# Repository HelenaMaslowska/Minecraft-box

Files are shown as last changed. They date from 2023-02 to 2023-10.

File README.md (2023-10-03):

# Minecraft box
Minecraft box is made using Raspberry Pi Zero, Python, electronics detectors and cartoon. This is my project for studies and first one using Raspberry Pi! It tooks about 2 weeks.

### So, how it works:
1. First of all you need to put your card on the right and RFID detects if your card is valid.
2. Secondly you need to choose your minibox from 1 to 4 on your phone.
3. Thirdly write your numbers from your phone to the box and box checks if your type it correctly.
4. If password had been written corretly the minibox opens!
5. The box automatically close.

<p align="center">

<p>

## Plans, scheme
1. [plans](https://github.com/HelenaMaslowska/Minecraft-box/blob/main/Scheme/plan.png) (written in polish) - explain plan for connections between devices 
2. [state machine](https://github.com/HelenaMaslowska/Minecraft-box/blob/main/Scheme/Maszyna%20stan%C3%B3w.png) (written in polish) - explain plan of states
3. [scheme](https://github.com/HelenaMaslowska/Minecraft-box/blob/main/Scheme/scheme.png) - final version 

## Run these programs in startup
1. [server.py](https://github.com/HelenaMaslowska/Minecraft-box/blob/main/Programs/server.py)
2. [main.py](https://github.com/HelenaMaslowska/Minecraft-box/blob/main/Programs/main.py)

## Models
I made models which I printed on 3D Printer. Here is folder for them! [> folder <](https://github.com/HelenaMaslowska/Minecraft-box/tree/main/Models)

## Photos
You may see final and physical result of this project so here is some photos from inside the box:
<p align="center">
  
<br/>
<p align="left">And here is Raspberry Pi:<p>
<p align="center">
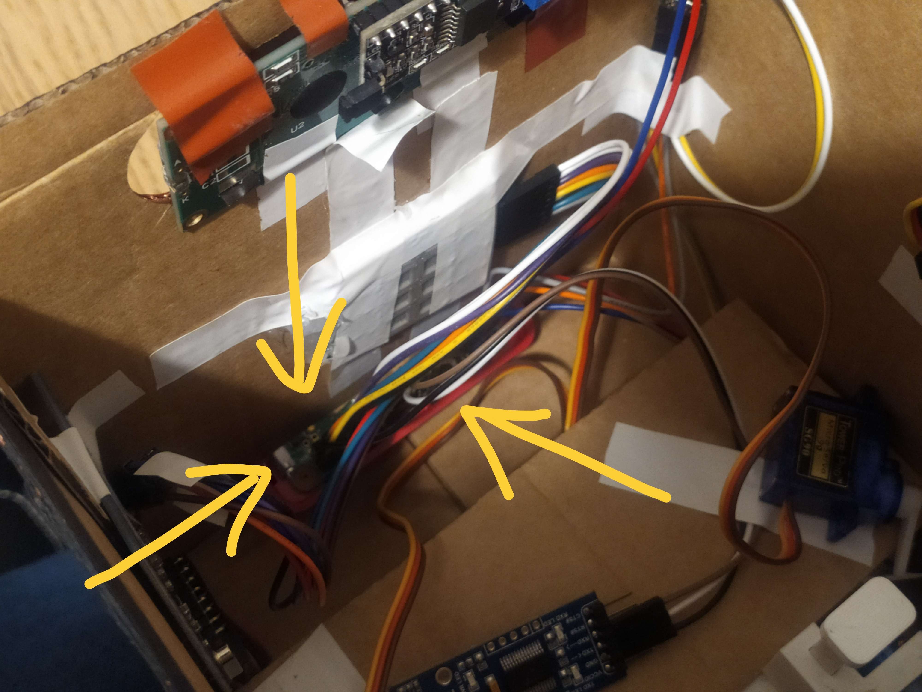
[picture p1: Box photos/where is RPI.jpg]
  
<p>

Outside the box:
<p align="center">

<br/>

<br/>
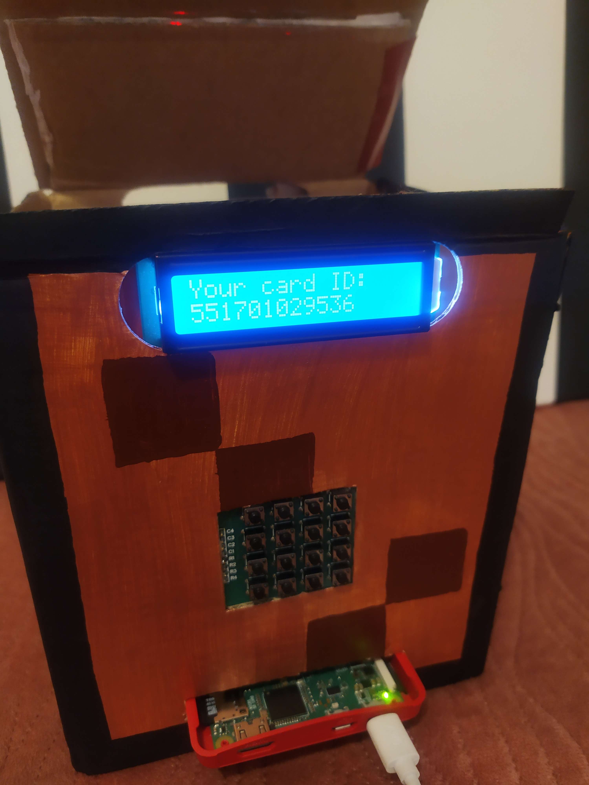
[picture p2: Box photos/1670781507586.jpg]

<p>

And the app:
<p align="center">
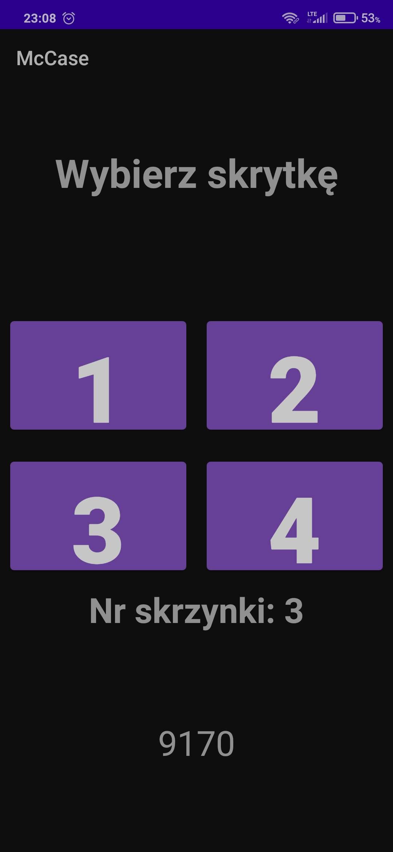
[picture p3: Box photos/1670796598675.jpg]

<p>
  
## Authors
- All electronics and graphics stuff, plans, state machine and scheme - Helena Masłowska
- Phone app - Łukasz Jankowski
  
Dec 2022

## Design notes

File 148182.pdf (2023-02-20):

### Laboratorium z przedmiotu Systemy wbudowane (SW) Sprawozdanie

Nazwa projektu: Skrzynka-self z Minecrafta

Prowadzący: Ariel Antonowicz | Autorzy: 148182 148081 150251 | Grupa dziekańska: | i5.1
| | Ocena:

Cel projektu:

Stworzenie skrzynki na przedmioty zabezpieczone jednorazowo wygenerowanym hasłem z telefonu (na zasadzie blik). Łączymy się za pomocą Wi-Fi i wpisujemy hasło, które następnie otwiera odpowiednią skrytkę. Skrytki nie mogą być otwarte jednocześnie. Buzzer odpala się 3 sekundy przed zamknięciem i kiedy zostało wpisane nieprawidłowe hasło.

Schemat:

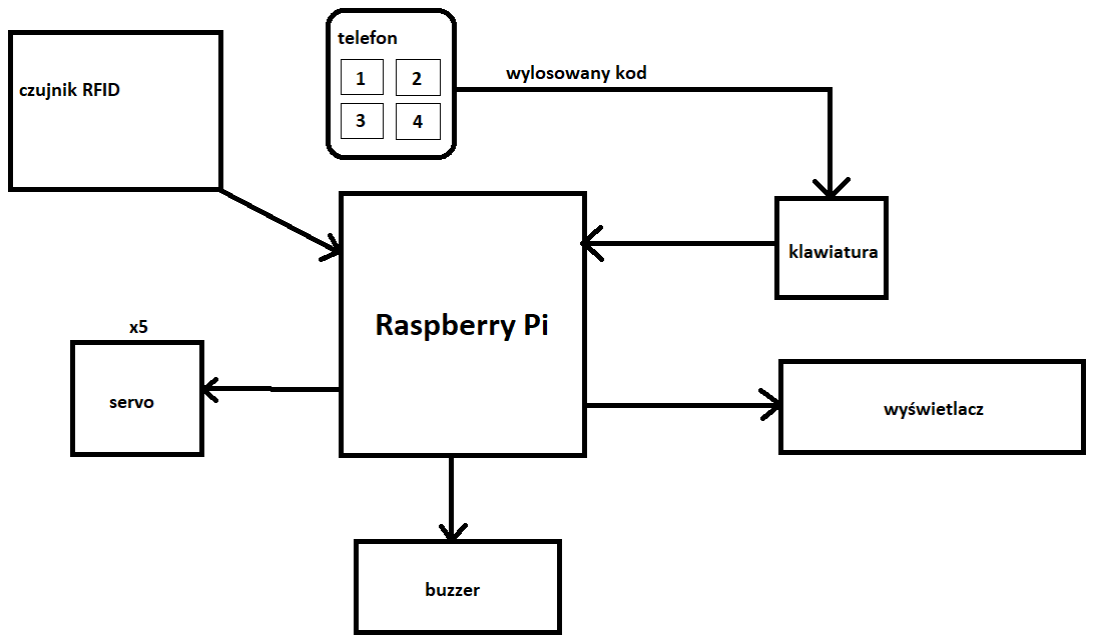
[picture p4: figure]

Wykorzystana platforma sprzętowa, czujniki pomiarowe, elementy wykonawcze:

servo x5, klawiatura, czujnik RFID, aplikacja na telefonie, buzzer

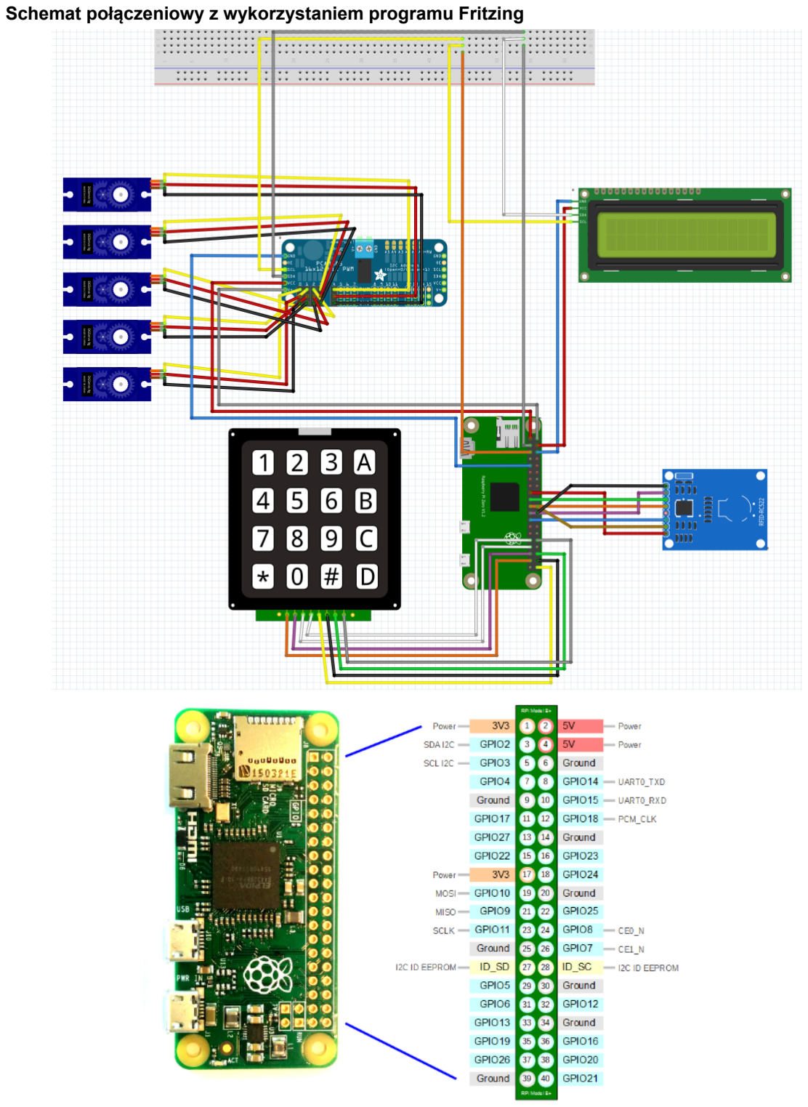
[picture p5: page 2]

Schemat połączeniowy z wykorzystaniem programu Fritzing

Wykorzystane elementy
- 1x Czytnik kart RFID RC522
- 1x 16 kanałowy servo motor driver
- 1x Wyświetlacz LCD 16X2 Alphanumeric Display
- 1x Raspberry Pi Zero W
- 1x 16-klawiszowa klawiatura 4x4 DWT-0261
- 3x Małe Servo SG90 9g
- 1x Małe ServoTG9e 9g
- 1x Duże Servo ACOMS AS-12

Projekt a realizacja
Z początku wgraliśmy na kartę SD Raspberry Pi OS. Następnie podłączyliśmy kartę do Raspberry Pi Zero W, które umożliwia łączenie się poprzez sieć Wi-Fi. Zamontowaliśmy czujniki i większość elementów. Mieliśmy problem z Pythonem (odinstalowano go, po czym zainstalowano, ale nie była to najlepsza decyzja). Pomogło ponowne wgranie systemu na kartę SD. Trzeba też było odpowiednio skonfigurować wstępne ustawienia i opcje (co będzie pokazane niżej).
Wszystkie elementy celu zostały spełnione poza ostatnim - buzzerem. Uznaliśmy, że jeśli servo wydaje dźwięki przy otwieraniu to nie potrzeba innego dźwięku, który oznajmia że coś się dzieje ze skrzynką, ponadto wszystko jest wyświetlane na ekranie.
Nie spodziewaliśmy się, że zostanie wykorzystane aż tyle pinów w Raspberry Pi stąd pomysł z driverem do serv. Dzięki temu wszystkie serva spokojnie mieszczą się na urządzeniu, a można również dołączyć większą liczbę serv niż 4.
Do projektu chcieliśmy dołączyć również płytkę umożliwiającą korzystanie z Raspberry Pi przewodowo ale okazała się nieprzydatna. Cały program został właściwie stworzony przez Putty - protokół SSH dzięki któremu mogliśmy pracować zdalnie poprzez tunel przekierowujący IP do localhosta w Raspberry Pi. Aplikacja na telefon została napisana w Kotlinie. Połączenie odbywa się poprzez udostępnienie telefonu jako routera i podłączenie aplikacji do IP Raspberry Pi. Aplikacja postuje na serwerze, która jest na płytce informacje o numerze skrytki i kodzie do tej skrytki a RPi to odbiera.

Możliwości rozwoju projektu
Skrzynka jest prototypem, który przypomina paczkomat. Wystarczy kliknąć odpowiedni przycisk na telefonie, a skrytka sama się otworzy. Można powiedzieć że stworzyliśmy paczkomat v2 z 4 skrytkami.

Najważniejsze fragmenty kodu z komentarzami

Pobrane biblioteki i inicjalizacja zmiennych

#!/usr/bin/python

# ------------ LIBRARIES SECTION ------------import time

import RPi.GPIO as GPIO
# server

import requests
# rfid

from mfrc522 import SimpleMFRC522 # LCD
from rpi_lcd import LCD
# keyboard

from pad4pi import rpi_gpio # servo driver
GPIO.setmode(GPIO.BCM)
GPIO.setwarnings(False)
import board
import busio
import adafruit_pca9685
from adafruit_servokit import ServoKit

# ------------ STARTER PACK STUFF SECTION ------------i2c = busio.I2C(board.SCL, board.SDA)

pca = adafruit_pca9685.PCA9685(i2c) | # driver
kit = ServoKit(channels=16) | # driver
pca.frequency = 50 | # set frequency for servos driver
card = SimpleMFRC522() | # rfid
lcd = LCD(address=0x3f) | # lcd
keyboard = "" | # keyboard input
KEYPAD = [
["1","2","3","A"],
["4","5","6","B"],
["7","8","9","C"],
["*","0","#","D"]
]
ROW_PINS = [21, 20, 16, 12] | # set pins BCM mode
COL_PINS = [26, 19, 13, 6] | # set pins BCM mode
factory = rpi_gpio.KeypadFactory()
keypad = factory.create_keypad(keypad=KEYPAD,row_pins=ROW_PINS, col_pins=COL_PINS, gpio_mode=GPIO.BCM)

Aktywacja klawiatury z dołączonej biblioteki

def activate_keyboard():
keypad.registerKeyPressHandler(key_pressed)

def key_pressed(key):
global keyboard
try:
keyboard += str(key)
except ValueError:
print("F")

Pobieranie danych z serwera

def get_from_server():
global server, case, code, if_open
server = eval(requests.get("http://0.0.0.0:8183").text) code, case = str(server['code']), int(server['case'])

Główny program

activate_keyboard() | # włączono odczytywanie klawiatury
while True:
set_servos() | # wyzerowanie pozycji serv na stan początkowy
try:
while str(keyboard) == "" or str(keyboard[len(keyboard)-1]) not in exit_btns: # tylko ostatnia litera inputu umożliwia wyjście ze skrzynki lcd_text("Hi! ", 1)
lcd_text("Put your card!", 2)
id, text = card.read() | # oczekiwanie na kartę
lcd_show_card_id()
if id == 551701029536: | # odczytywanie tylko jednej karty
id = 0
open_box() | # otworzenie skrzynki
time.sleep(4)
while str(keyboard) == "" or str(keyboard[len(keyboard)-1]) not in exit_btns:
get_from_server() # pobranie ostatnio wygenerowanego kodu check_if_wrong_password() # sprawdzenie czy wejście nie
# przekroczyło długości ciągu 4 cyfrowego PINu

lcd_show_password() | # odświeżenie ekranu
time.sleep(0.5) | # by nie zajmować zbytnio procesora

if str(code) == str(keyboard):
# post_info_to_the_server(code, case, "cant")

keyboard = ""
open_for_x_seconds(8) # ograniczony czas otwarcia skrzynki lcd_text("Thats all! ", 1)
lcd_text("THX!", 2)
time.sleep(3) | # chwila na przeczytanie tekstu

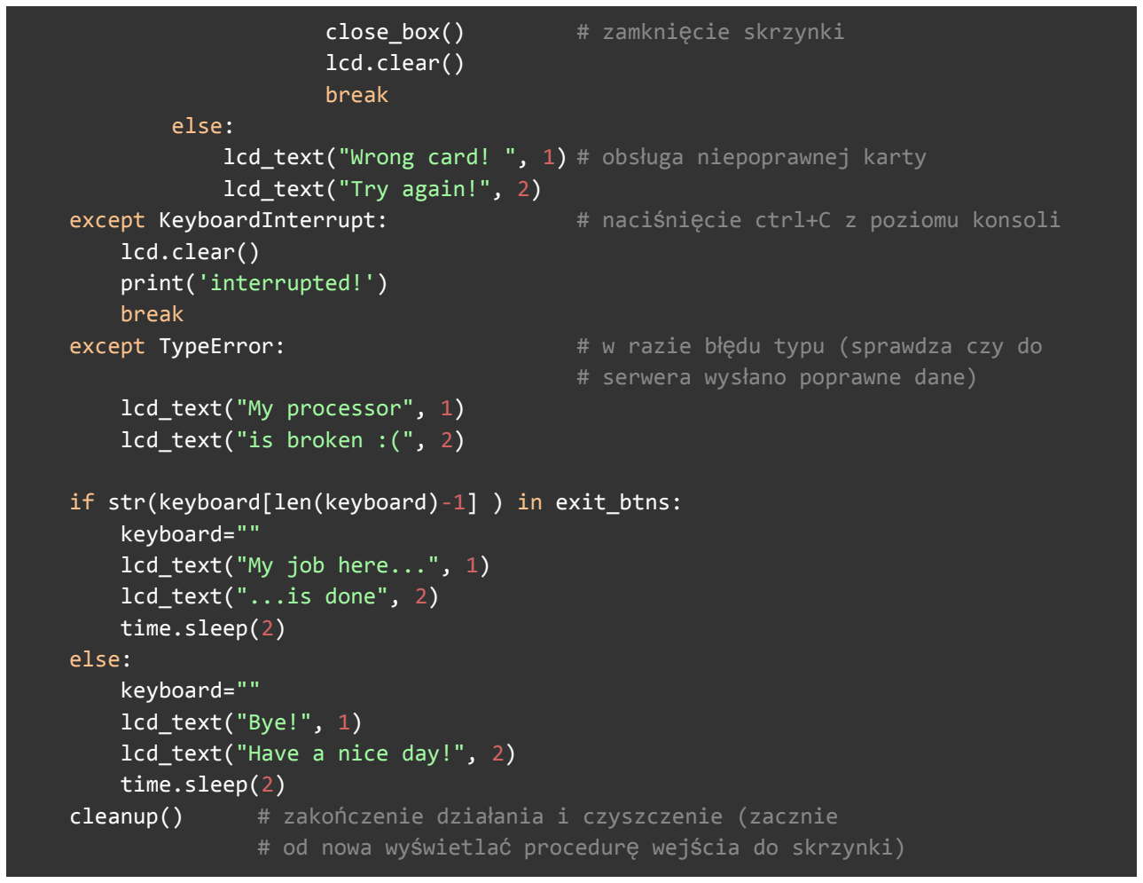
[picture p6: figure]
close_box(); # zamknięcie skrzynki; lcd.clear() break; else:; lcd_text("Try again!", 2); lcd.clear() print('interrupted!') break; # serwera wysłano poprawne dane); lcd_text("My processor", 1) lcd_text("is broken :(", 2); keyboard="" lcd_text("My job here...", 1) lcd_text("...is done", 2) time.sleep(2) else: keyboard="" lcd_text("Bye!", 1) lcd_text("Have a nice day!", 2) time.sleep(2)

lcd_text("Wrong card! ", 1) # obsługa niepoprawnej karty

except KeyboardInterrupt: | # naciśnięcie ctrl+C z poziomu konsoli
except TypeError: | # w razie błędu typu (sprawdza czy do

if str(keyboard[len(keyboard)-1] ) in exit_btns:

cleanup() | # zakończenie działania i czyszczenie (zacznie # od nowa wyświetlać procedurę wejścia do skrzynki)

Uruchamiamy skrzynkę za pomocą funkcji

def open_box():
kit.continuous_servo[0].throttle = 1

Uruchamiamy również serwer z odrębnego pliku server.py

# uruchomienie serwera

with socketserver.TCPServer(("0.0.0.0", PORT), MyServer) as httpd: print("serving at 0.0.0.0:{}".format(PORT)) httpd.serve_forever()

Tutaj należało udostępnić opcje I2, I4, I5, które umożliwiały prawidłowe działanie SSH, I2C, SPI

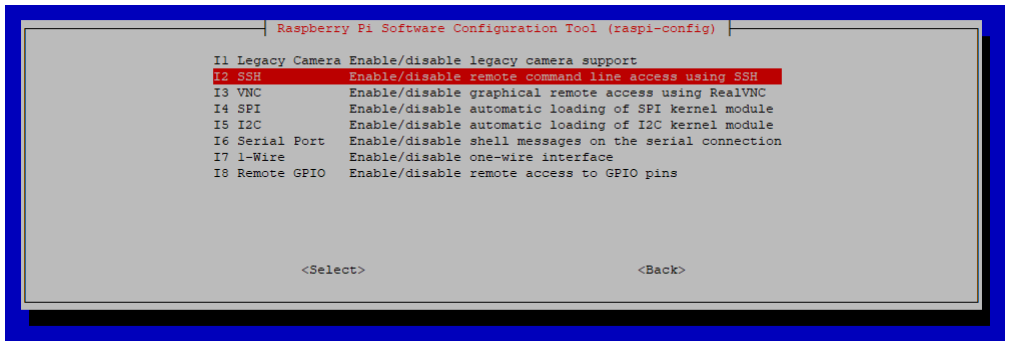
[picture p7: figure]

Autostart
Za pomocą komendy sudo nano /etc/rc.local należało dodać aplikacje autostartu.

sudo python /home/helena/server.py &
sudo python /home/helena/main.py 2>&1 | tee /home/helena/log.txt &
log.txt informował o ewentualnych błędach programu

Wi-Fi
Bardzo ważnym elementem było dodanie do wpa_supplicant.conf linijki informującej o dodatkowym Wi-Fi, dzięki czemu RPi łączy się automatycznie z pierwszą napotkaną siecią, a w razie niepowodzenia z kolejną zapisaną w pliku.

Osiągnęliśmy to poleceniem:
sudo nano /etc/wpa_supplicant/wpa_supplicant.conf

network={
ssid="Test Wifi Network"
psk="SecretPassWord"
}

Zdjęcia skrzynki - przykładowe napisy na skrzynce i zawartość pudełka

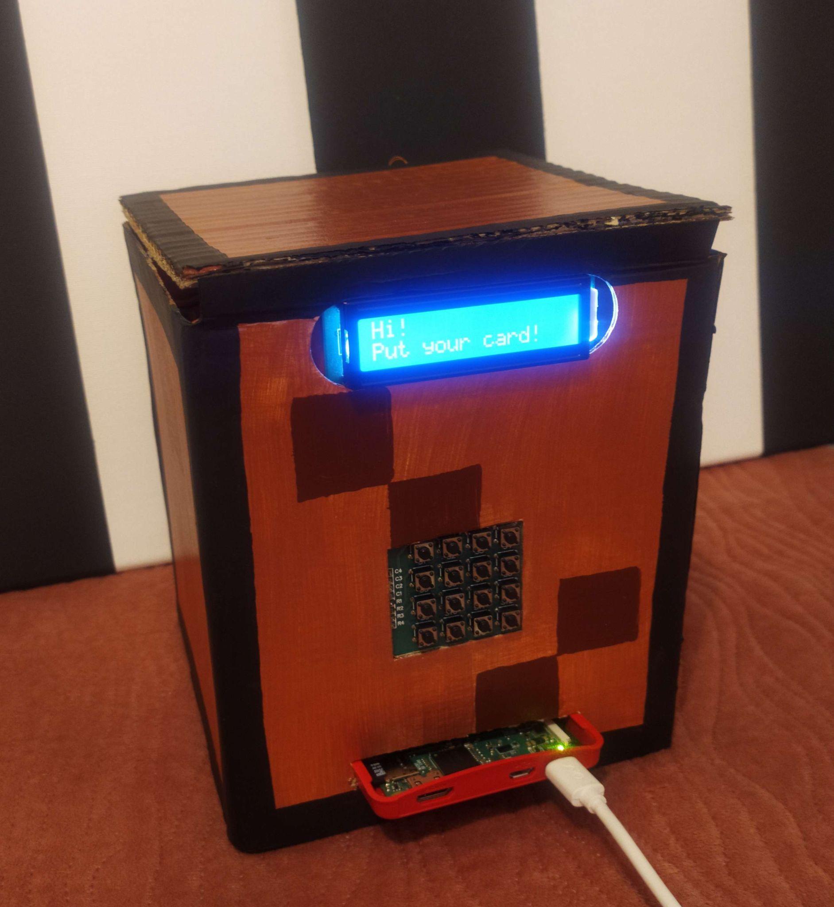
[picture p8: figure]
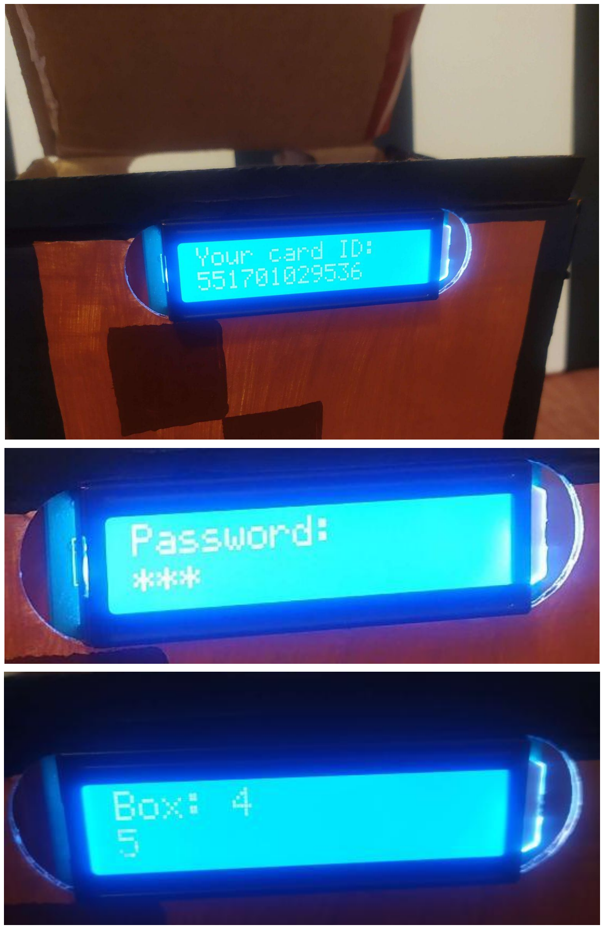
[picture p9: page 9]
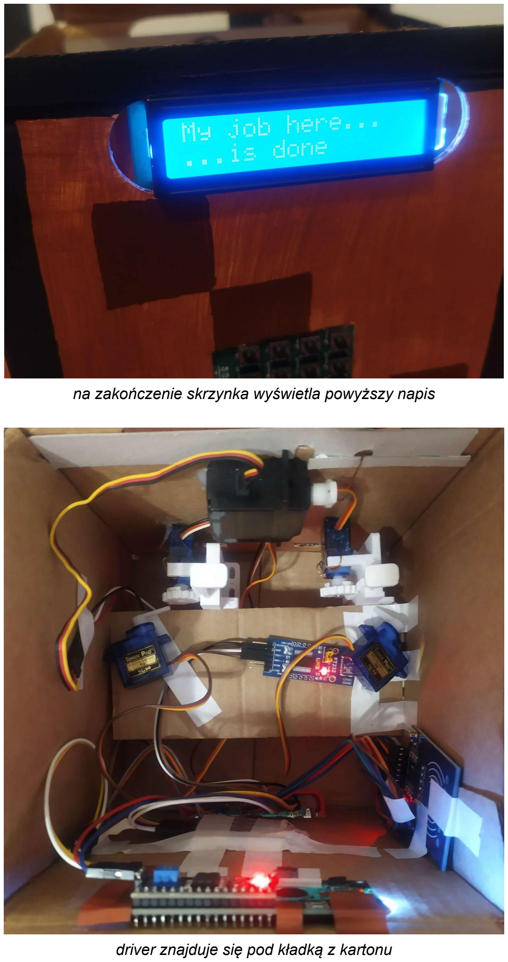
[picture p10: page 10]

na zakończenie skrzynka wyświetla powyższy napis

driver znajduje się pod kładką z kartonu

Zdjęcia elementów i przewodów na płytce uniwersalnej w fazie testów

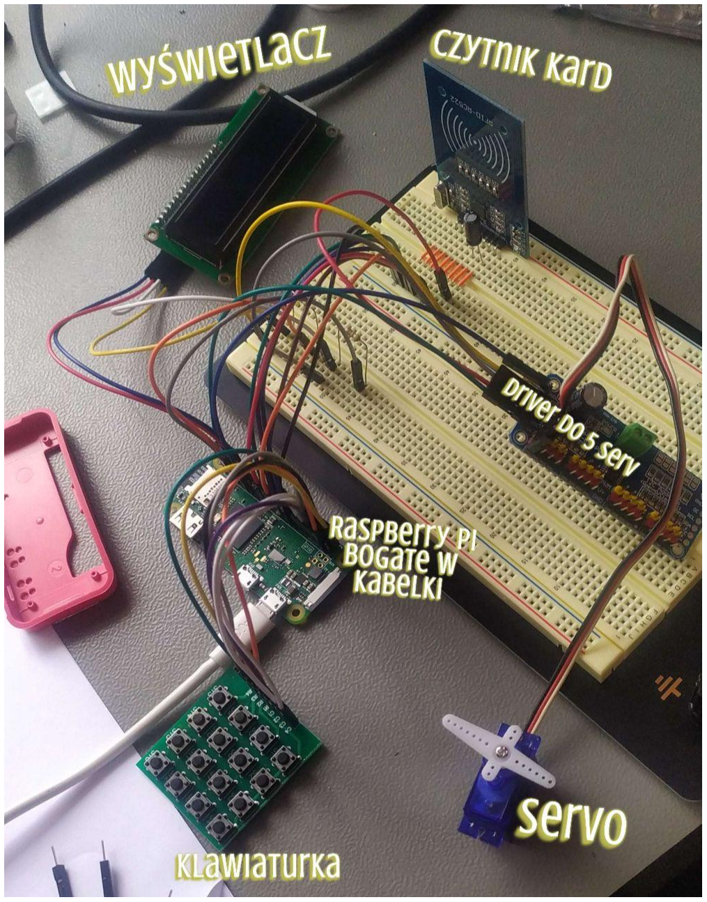
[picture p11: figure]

Zrzut ekranu aplikacji

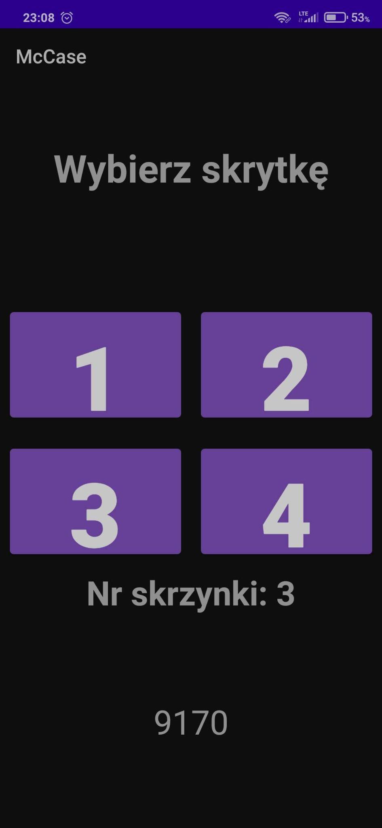
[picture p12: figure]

Podsumowanie i wnioski

Projekt zdecydowanie przybliżył nam działanie płytki Raspberry Pi i jej potencjał. Wystarczy odpowiedni czujnik i odpowiednie elementy wykonawcze aby stworzyć za pomocą niepozornego komputerka system, który może być stosowany w domu. Pracy było sporo, jeszcze więcej było błędów, ale po 2 tygodniach zadanie udało się wykonać.

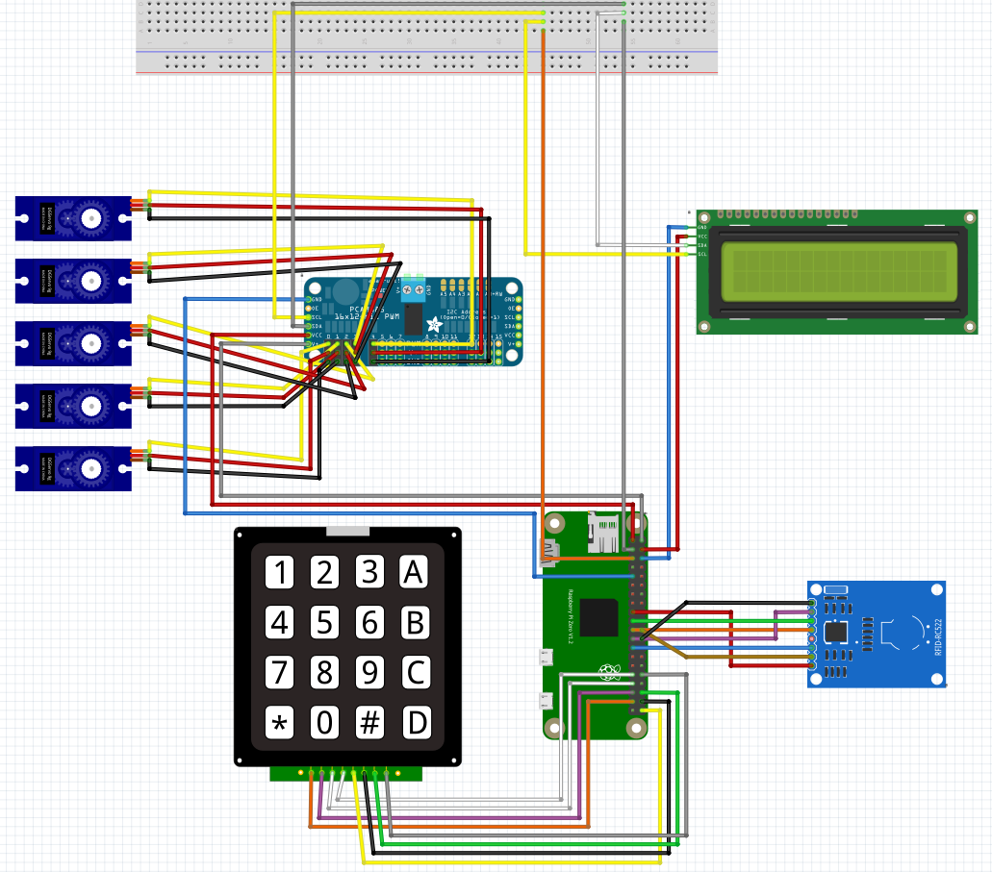
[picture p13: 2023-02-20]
Scheme/scheme.png

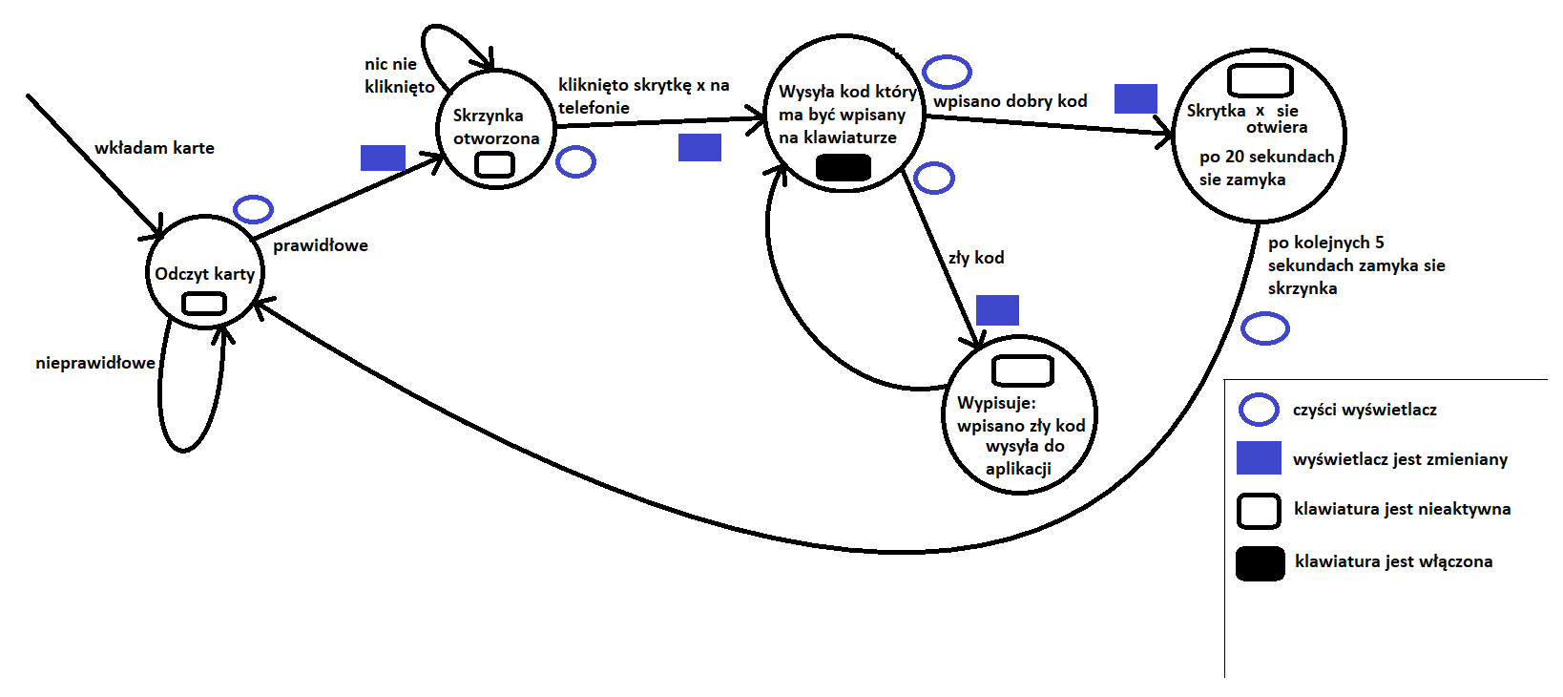
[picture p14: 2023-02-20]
Scheme/Maszyna stanów.png

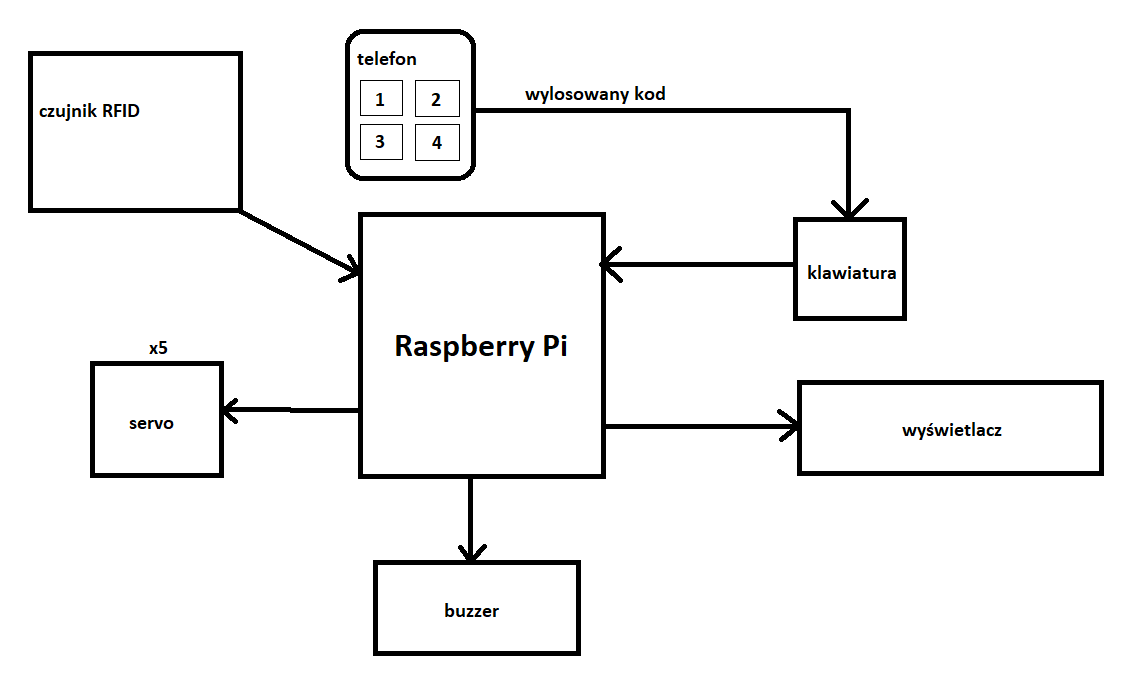
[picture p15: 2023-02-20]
Scheme/plan.png

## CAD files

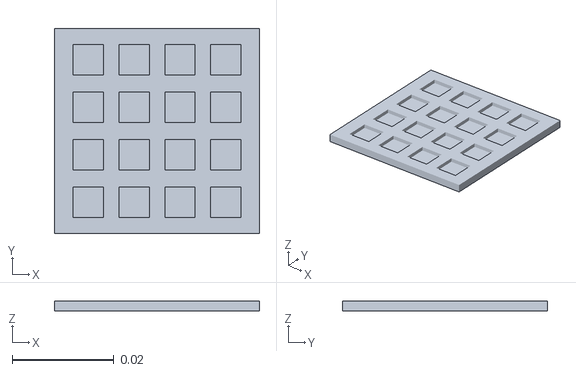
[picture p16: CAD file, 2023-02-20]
Models/keyboard.stl
0.0403 x 0.0403 x 0.00196

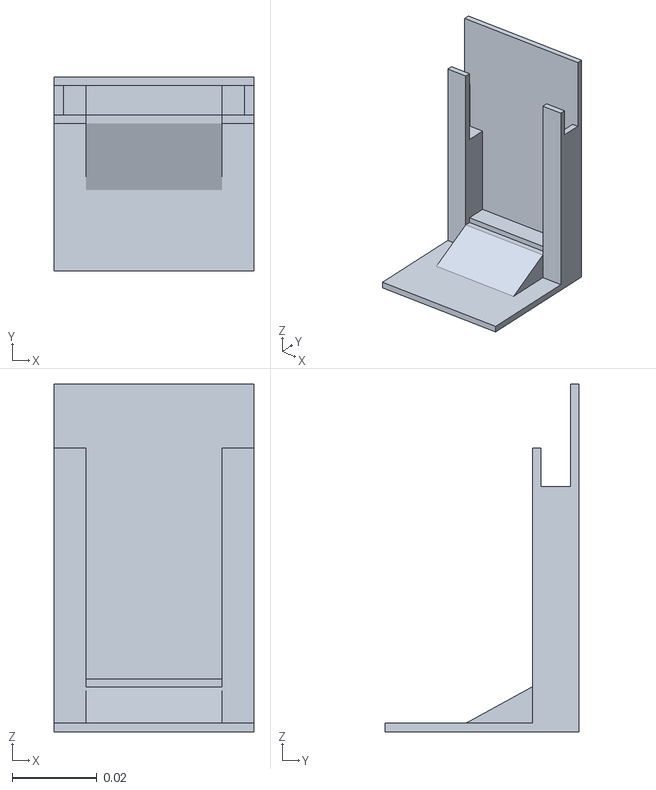
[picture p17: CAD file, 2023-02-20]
Models/RFID stand/rfid_stand.stl
0.047 x 0.0457 x 0.0821

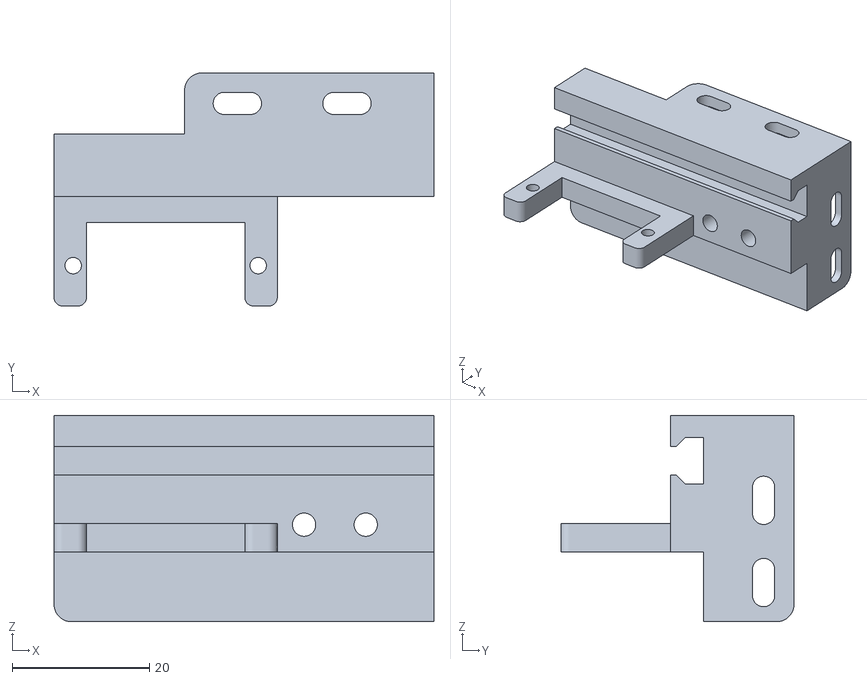
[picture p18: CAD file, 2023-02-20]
Models/Servo powerups/servo_obudowa.stl
55.5 x 34.0 x 30.1

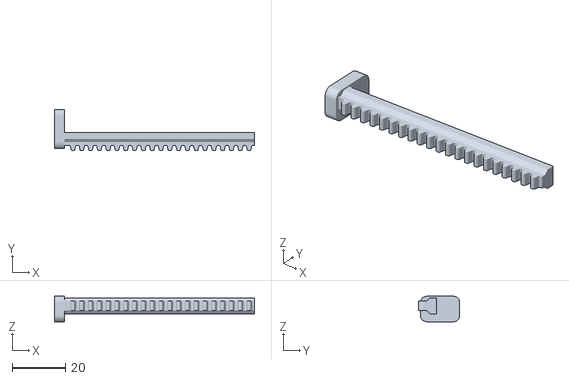
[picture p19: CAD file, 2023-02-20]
Models/Servo powerups/tape.stl
75.0 x 15.5 x 9.60

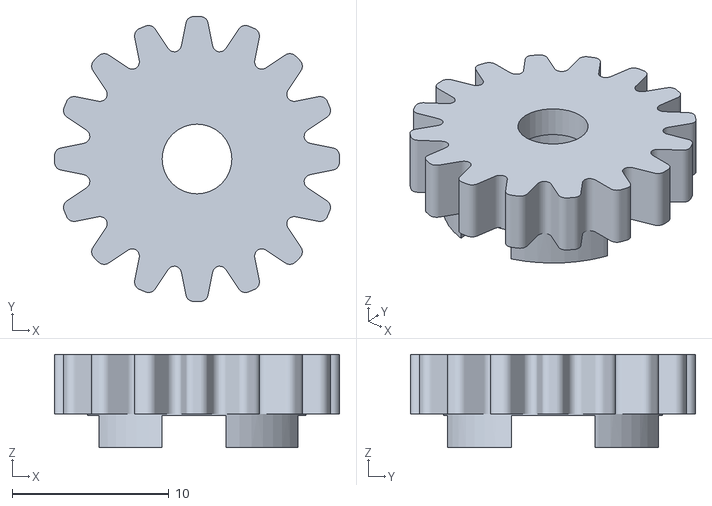
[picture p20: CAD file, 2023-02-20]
Models/Servo powerups/sruba.stl
18.2 x 18.2 x 5.97

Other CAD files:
Models/RFID stand/rfid_stand.blend
Models/Servo powerups/servo tape.blend
Models/Servo powerups/servo_obudowa.blend
Models/Servo powerups/servo_sruba.blend

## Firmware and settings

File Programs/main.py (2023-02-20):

#!/usr/bin/python

# ------------ LIBRARIES SECTION ------------
import time
import RPi.GPIO as GPIO
# server
import requests
# rfid
from mfrc522 import SimpleMFRC522
# LCD
from rpi_lcd import LCD
# keyboard
from pad4pi import rpi_gpio
# servo driver
GPIO.setmode(GPIO.BCM)
GPIO.setwarnings(False)
import board
import busio
import adafruit_pca9685
from adafruit_servokit import ServoKit

# ------------ STARTER PACK STUFF SECTION ------------
i2c = busio.I2C(board.SCL, board.SDA)
pca = adafruit_pca9685.PCA9685(i2c)		# driver
kit = ServoKit(channels=16)				# driver
pca.frequency = 50 						# set frequency for servos driver
card = SimpleMFRC522() 					# rfid
lcd = LCD(address=0x3f) 				# lcd

keyboard = ""							# keyboard input
KEYPAD = [
	["1","2","3","A"],
	["4","5","6","B"],
	["7","8","9","C"],
	["*","0","#","D"]
	]
ROW_PINS = [21, 20, 16, 12] 			# BCM 
COL_PINS = [26, 19, 13, 6] 				# BCM 
factory = rpi_gpio.KeypadFactory()
keypad = factory.create_keypad(keypad=KEYPAD,row_pins=ROW_PINS, col_pins=COL_PINS, gpio_mode=GPIO.BCM)

# ------------ SERVER VARIABLES ------------
server = "0000"			# info from and to the server
code = "2111"
case = 1 			
exit_btns = ("*", "A", "B", "C", "D")

# ------------ TEST SECTION TEMP SECTION ------------
requests.post("http://localhost:8183", "{'code':2111, 'case':0, 'box':0}")
#password = requests.get("http://localhost:8183").text
#print(password)

def key_pressed(key):
	global keyboard
	try:
		keyboard += str(key)
	except ValueError:
		print("F")

def activate_keyboard():
	keypad.registerKeyPressHandler(key_pressed)

def deactive_keyboard():
	keypad.unregisterKeyPressHandler(key_pressed)

def lcd_text(text, num):			# text with space filler
	leng = 16-len(text)
	lcd.text(text + leng*" ", num)

def check_if_wrong_password():
	global keyboard
	if len(keyboard) >= 4:
		if code != keyboard:
			lcd_text("Wrong password!", 1)
			lcd_text("Wait 3 sec >:(", 2)	
			time.sleep(3)				
		keyboard = ""


def lcd_show_card_id():
	print("Card ID: ", str(id))
	lcd_text("Your card ID:", 1)
	lcd_text(str(id), 2)

def lcd_timer(timer):
	for i in range(timer,0,-1):
		lcd_text("Box: " + str(case), 1)
		lcd_text(str(i), 2)
		time.sleep(1)

def lcd_show_password():
	lcd_text("Password: ", 1)
	lcd_text(len(keyboard)*"*", 2)
	
def open_for_x_seconds(timer):
	kit.continuous_servo[case].throttle = 1
	lcd_timer(timer)
	kit.continuous_servo[case].throttle = -1
	time.sleep(1)

def open_box():
	kit.continuous_servo[0].throttle = 1

def close_box():
	kit.continuous_servo[0].throttle = -1

def get_from_server():
	global server, case, code
	server = eval(requests.get("http://localhost:8183").text)
	code, case= str(server['code']), int(server['case'])


def post_info_to_the_server(code: int, case: int, box: str):
	try:
		if box == "can":
			msg = "{'code':" + str(code) + ", 'case':" + str(case) + ", 'box':1}"
		elif box == "cant":
			msg = "{'code':" + str(code) + ", 'case':" + str(case) + ", 'box':0}"
		else:
			raise ValueError
		requests.post("http://localhost:8183", msg)
	except ValueError:
		print("error")

try:
	while str(keyboard) not in exit_btns:
		lcd_text("Hi! ", 1)
		lcd_text("Put your card!", 2)		
		id, text = card.read()
		lcd_show_card_id()	
		if id == 551701029536:
			id = 0
			open_box()			
			post_info_to_the_server(code, case, "can")
			time.sleep(3)		# show 
			activate_keyboard()		
			while str(keyboard) not in exit_btns:		
				#server = eval(requests.get("http://localhost:8183").text)
				get_from_server()
				check_if_wrong_password()
				lcd_show_password()
				time.sleep(1)
				if str(code) == str(keyboard):
					post_info_to_the_server(code, case, "cant")
					deactive_keyboard()
					keyboard = ""
					open_for_x_seconds(10)
					lcd_text("Thats all! ", 1)
					lcd_text("THX!", 2)		
					time.sleep(5)		
					close_box()
					lcd.clear()
					break
			else:
				deactive_keyboard()
		else:
			lcd_text("Wrong card! ", 1)
			lcd_text("Try again!", 2)	
	else:
		deactive_keyboard()
except KeyboardInterrupt:
	lcd.clear()
	print('interrupted!')
except TypeError:
	lcd_text("My processor", 1)
	lcd_text("is broken :(", 2)	
finally:
	if str(keyboard) in exit_btns:
		lcd_text("My job here...", 1)
		lcd_text("...is done", 2)			
	else:
		lcd_text("Bye!", 1)			
		lcd_text("Have a nice day!", 2)
GPIO.cleanup()

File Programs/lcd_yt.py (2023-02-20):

import smbus
import time
# Define some device parameters
I2C_ADDR  = 0x3f # I2C device address
LCD_WIDTH = 16   # Maximum characters per line

# Define some device constants
LCD_CHR = 1 # Mode - Sending data
LCD_CMD = 0 # Mode - Sending command

LCD_LINE_1 = 0x80 # LCD RAM address for the 1st line
LCD_LINE_2 = 0xC0 # LCD RAM address for the 2nd line
LCD_LINE_3 = 0x94 # LCD RAM address for the 3rd line
LCD_LINE_4 = 0xD4 # LCD RAM address for the 4th line

LCD_BACKLIGHT  = 0x08  # On
ENABLE = 0b00000100 # Enable bit

# Timing constants
E_PULSE = 0.0005
E_DELAY = 0.0005

#Open I2C interface
bus = smbus.SMBus(1)

def lcd_init():
  # Initialise display
  lcd_byte(0x33,LCD_CMD) # 110011 Initialise
  lcd_byte(0x32,LCD_CMD) # 110010 Initialise
  lcd_byte(0x06,LCD_CMD) # 000110 Cursor move direction
  lcd_byte(0x0C,LCD_CMD) # 001100 Display On,Cursor Off, Blink Off 
  lcd_byte(0x28,LCD_CMD) # 101000 Data length, number of lines, font size
  lcd_byte(0x01,LCD_CMD) # 000001 Clear display
  time.sleep(E_DELAY)

def lcd_byte(bits, mode):
  # Send byte to data pins
  # bits = the data
  # mode = 1 for data
  #        0 for command

  bits_high = mode | (bits & 0xF0) | LCD_BACKLIGHT
  bits_low = mode | ((bits<<4) & 0xF0) | LCD_BACKLIGHT

  # High bits
  bus.write_byte(I2C_ADDR, bits_high)
  lcd_toggle_enable(bits_high)

  # Low bits
  bus.write_byte(I2C_ADDR, bits_low)
  lcd_toggle_enable(bits_low)

def lcd_toggle_enable(bits):
  # Toggle enable
  time.sleep(E_DELAY)
  bus.write_byte(I2C_ADDR, (bits | ENABLE))
  time.sleep(E_PULSE)
  bus.write_byte(I2C_ADDR,(bits & ~ENABLE))
  time.sleep(E_DELAY)

def lcd_string(message,line):
  # Send string to display

  message = message.ljust(LCD_WIDTH," ")

  lcd_byte(line, LCD_CMD)

  for i in range(LCD_WIDTH):
    lcd_byte(ord(message[i]),LCD_CHR)

def main():
  # Main program block

  # Initialise display
  lcd_init()
  # Send some test
  while True:
  	lcd_string("RPi LCD tutorial",LCD_LINE_1)
  	lcd_string("   kolejny ",LCD_LINE_2)

if __name__ == '__main__':

  try:
    main()
  except KeyboardInterrupt:
    pass
  finally:
    lcd_byte(0x01, LCD_CMD)

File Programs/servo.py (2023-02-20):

import time
from gpiozero import Servo
from board import SCL, SDA
import busio

# Import the PCA9685 module. Available in the bundle and here:
#   https://github.com/adafruit/Adafruit_CircuitPython_PCA9685
from adafruit_motor import servo
from adafruit_pca9685 import PCA9685

i2c = busio.I2C(SCL, SDA)

# Create a simple PCA9685 class instance.
pca = PCA9685(i2c, address=0x40)
# You can optionally provide a finer tuned reference clock speed to improve the accuracy of the
# timing pulses. This calibration will be specific to each board and its environment. See the
# calibration.py example in the PCA9685 driver.
# pca = PCA9685(i2c, reference_clock_speed=25630710)
pca.frequency = 60

# To get the full range of the servo you will likely need to adjust the min_pulse and max_pulse to
# match the stall points of the servo.
# This is an example for the Sub-micro servo: https://www.adafruit.com/product/2201
# servo7 = servo.Servo(pca.channels[7], min_pulse=580, max_pulse=2350)
# This is an example for the Micro Servo - High Powered, High Torque Metal Gear:
#   https://www.adafruit.com/product/2307
# servo7 = servo.Servo(pca.channels[7], min_pulse=500, max_pulse=2600)
# This is an example for the Standard servo - TowerPro SG-5010 - 5010:
#   https://www.adafruit.com/product/155
# servo7 = servo.Servo(pca.channels[7], min_pulse=400, max_pulse=2400)
# This is an example for the Analog Feedback Servo: https://www.adafruit.com/product/1404
# servo7 = servo.Servo(pca.channels[7], min_pulse=600, max_pulse=2500)
# This is an example for the Micro servo - TowerPro SG-92R: https://www.adafruit.com/product/169
# servo7 = servo.Servo(pca.channels[7], min_pulse=500, max_pulse=2400)

# The pulse range is 750 - 2250 by default. This range typically gives 135 degrees of
# range, but the default is to use 180 degrees. You can specify the expected range if you wish:
servo7 = servo.Servo(pca.channels[7], actuation_range=135)
# servo7 = servo.Servo(pca.channels[7])

# We sleep in the loops to give the servo time to move into position.
for i in range(180):
    servo7.angle = i
    time.sleep(0.03)
for i in range(180):
    servo7.angle = 180 - i
    time.sleep(0.03)
print("done")
# You can also specify the movement fractionally.
fraction = 0.0
while fraction < 1.0:
    servo7.fraction = fraction
    fraction += 0.01
    time.sleep(0.03)

pca.deinit()
#servo = Servo(25)

#try:
#	while True:
#	servo.min()
#	sleep(0.5)
#	servo.mid()
#	sleep(0.5)#
#	servo.max()
#	sleep(0.5)
#except KeyboardInterrupt:
#	print("Program stopped")

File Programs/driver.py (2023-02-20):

import board
import busio
import time
import adafruit_pca9685
from adafruit_motor import servo
from adafruit_servokit import ServoKit
print(type(board.SCL))
i2c = busio.I2C(board.SCL, board.SDA)
pca = adafruit_pca9685.PCA9685(i2c)


### Blink LED on channel 0

#led_channel = pca.channels[0]

#pca.frequency = 60
#try:
#	while True:
#		led_channel.duty_cycle = 1000
#		time.sleep(2)
#		led_channel.duty_cycle = 20
#		time.sleep(2)
		#for i in range(0xffff):
	#		led_channel.duty_cycle = i
	#		time.sleep(0.1)
#except KeyboardInterrupt:
#	pass

### Set channels to the number of servo channels on your kit.
# 8 for FeatherWing, 16 for Shield/HAT/Bonnet.

kit = ServoKit(channels=8)
pca.frequency = 50

kit.servo[0].angle = 180
kit.continuous_servo[1].throttle = 1
time.sleep(1)
kit.continuous_servo[1].throttle = -1
time.sleep(1)
kit.servo[0].angle = 0
kit.continuous_servo[1].throttle = 0
